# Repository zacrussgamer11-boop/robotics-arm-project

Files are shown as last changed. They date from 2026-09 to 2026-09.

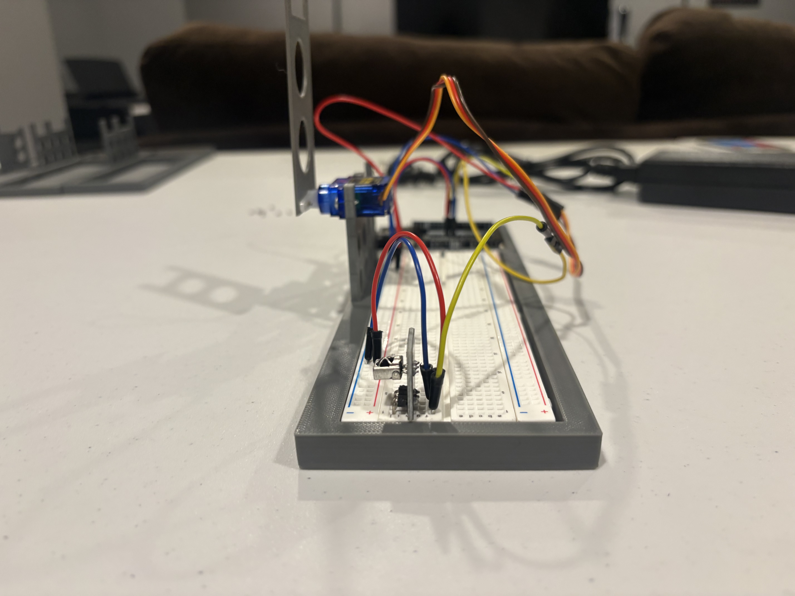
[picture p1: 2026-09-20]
project_info/V1 Complete/PHOTOS/IMG_8291.jpg

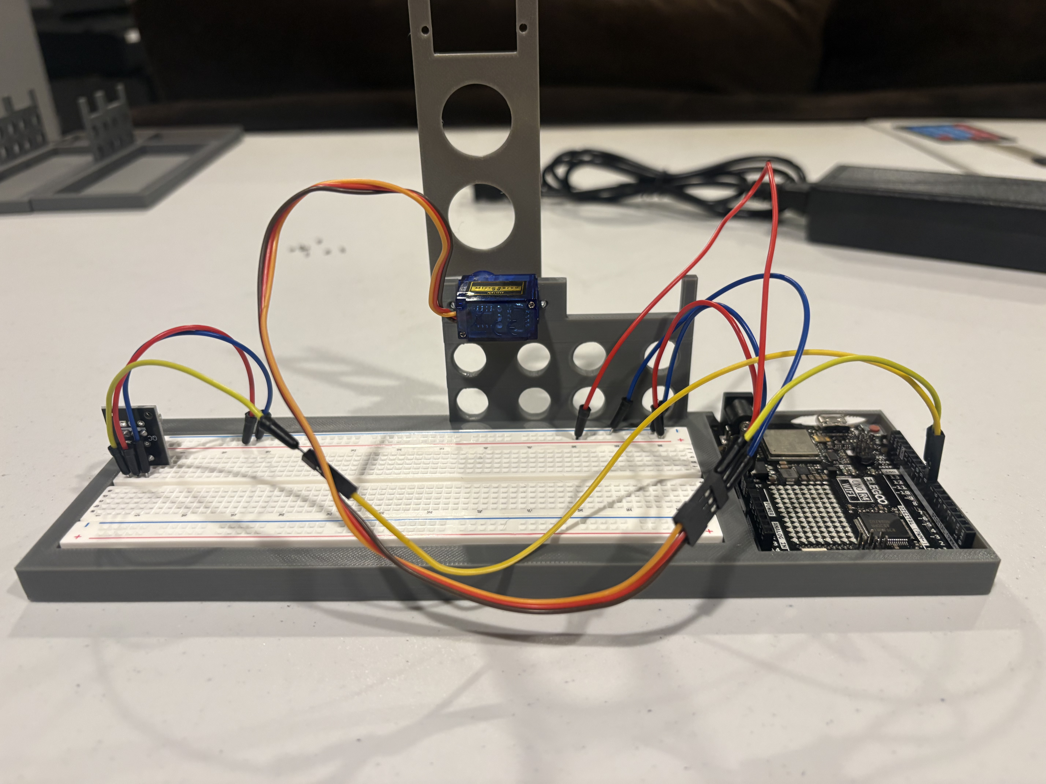
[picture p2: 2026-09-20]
project_info/V1 Complete/PHOTOS/IMG_8292.jpg

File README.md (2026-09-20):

# Robotics Arm Project

Built By zacrussgamer11
- Open Source for anybody to use
- Enjoy what I have built and use as a framework for your own projects!
- No promise anything will work as intended, everything you need will be included

Arduino UNO R4 WiFi robotics learning project.

## Current progress

- Learned breadboard basics
- Controlled an LED
- Used a pushbutton as input
- Read a potentiometer
- Controlled a servo with a potentiometer
- Added an LED movement indicator
- Added movement tolerance/deadband

## Current hardware

- Arduino UNO R4 WiFi
- Breadboard
- Potentiometer
- Servo motor
- LED
- 220 ohm resistor
- IR Sensor

## Current phase

Phase 1 - Single joint servo control

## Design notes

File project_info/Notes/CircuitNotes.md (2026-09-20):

# Build Notes - All Circuit Files can be found in the Hardware folder

## Version 1
    Plan - One servo moving a single arm forward and backwards being controlled by a remote control using a ir receiver

    ## Circuit V1
        ## IR Reciever
        - In the circuit diagram it uses a different model of IR, it is meant as representation of my circuit.
        - My Physical module uses G = GND, R = 5V, Y = signal (D8). Frontfacing the GND needs to be left most wire, PWR (5V) needs to be middle, and out needs to be most right. (If you are using this as a framework please check independently your own specific format)
        ## Servo
        - On the diagram the Signal and PWR terminals are swapped aswell, again please check your own framework and what connection points you have yourself.

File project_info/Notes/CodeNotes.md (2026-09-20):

## Code Notes

## V0.1 - Sep 19 - 1.38AM - Finished
    Initial Hardware Validation. Legacy proof of concept. Code deprecated, removed, and nonexistent. Potentiometer moved a servo which triggered a LED to light.

## V1 - Current

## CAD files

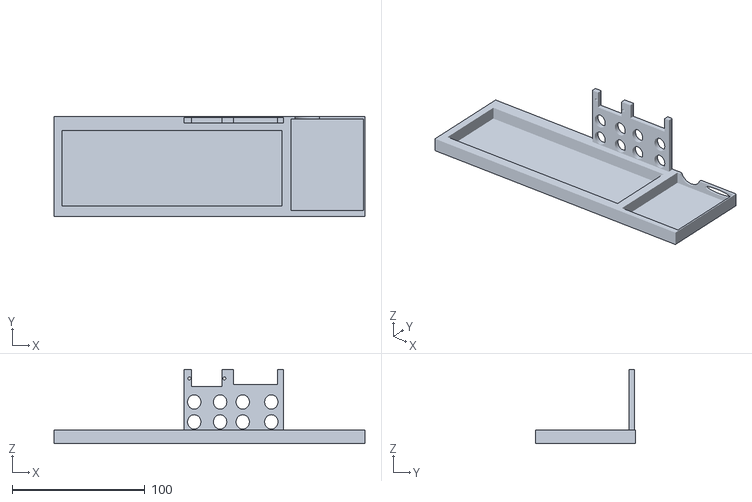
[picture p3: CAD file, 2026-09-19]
project_info/V1 Complete/HARDWARE/Mechanical/Base of robot/Base Mount V1.3.stl
234.0 x 75.5 x 56.0

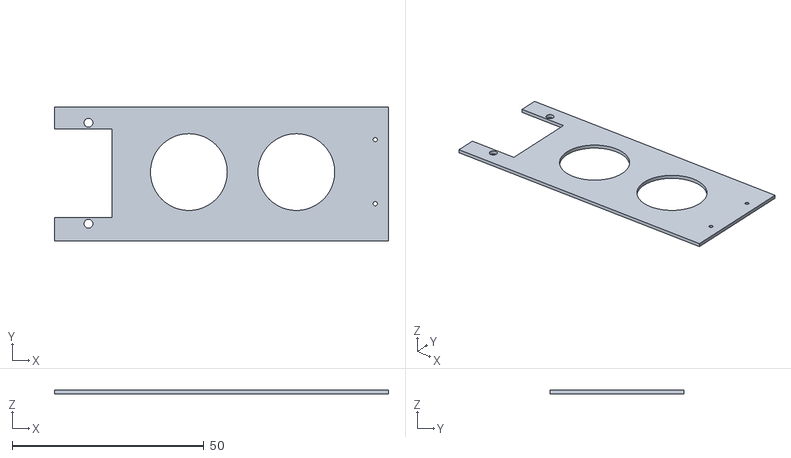
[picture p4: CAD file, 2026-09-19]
project_info/V1 Complete/HARDWARE/Mechanical/Joints/Joint 1/Joint 1 V1.2.stl
87.0 x 35.0 x 1.00

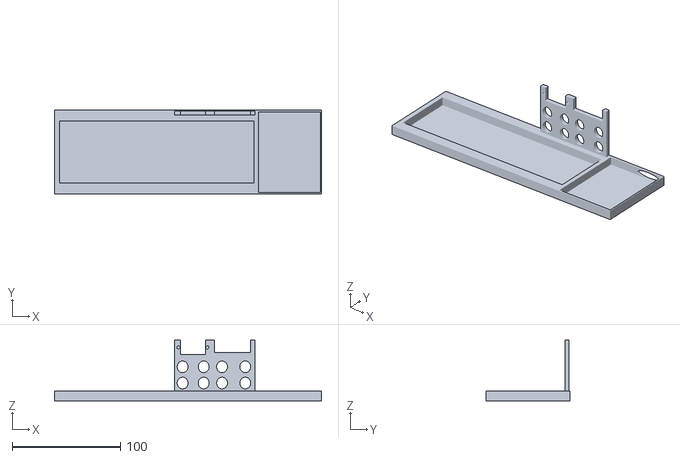
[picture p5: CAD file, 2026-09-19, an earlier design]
project_info/V1 Complete/HARDWARE/Mechanical/Base of robot/Base Mount V1.1.stl
247.0 x 78.0 x 56.0

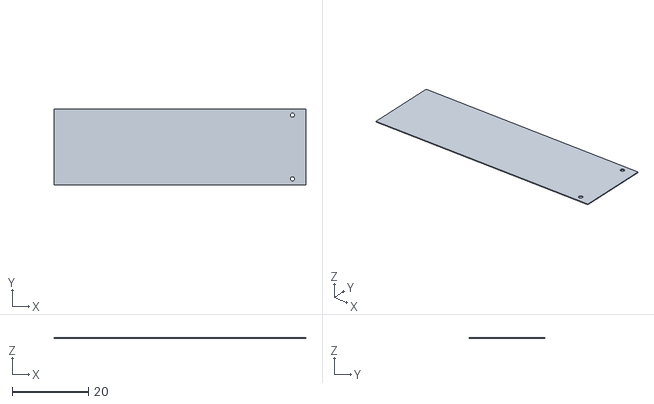
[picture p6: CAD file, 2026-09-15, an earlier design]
project_info/V1 Complete/HARDWARE/Mechanical/Joints/Joint 1/Joint 1 V1.stl
66.0 x 20.0 x 0.2

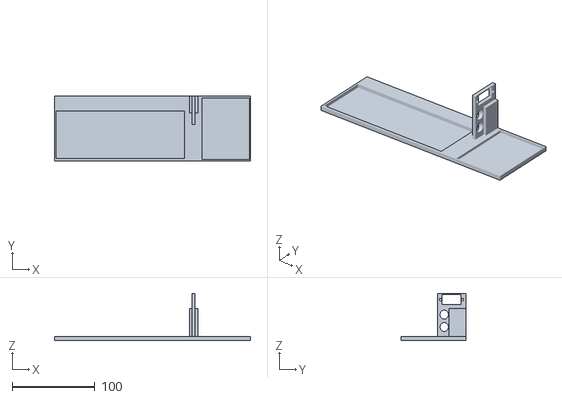
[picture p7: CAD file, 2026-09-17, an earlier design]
project_info/V1 Complete/HARDWARE/Mechanical/Base of robot/Base Mount V1.stl
237.0 x 78.0 x 57.0

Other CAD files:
project_info/V1 Complete/HARDWARE/Mechanical/Joints/Joint 1/Joint 1 V1.1.stl
project_info/V1 Complete/HARDWARE/Mechanical/Base of robot/Base Mount V1.2.stl

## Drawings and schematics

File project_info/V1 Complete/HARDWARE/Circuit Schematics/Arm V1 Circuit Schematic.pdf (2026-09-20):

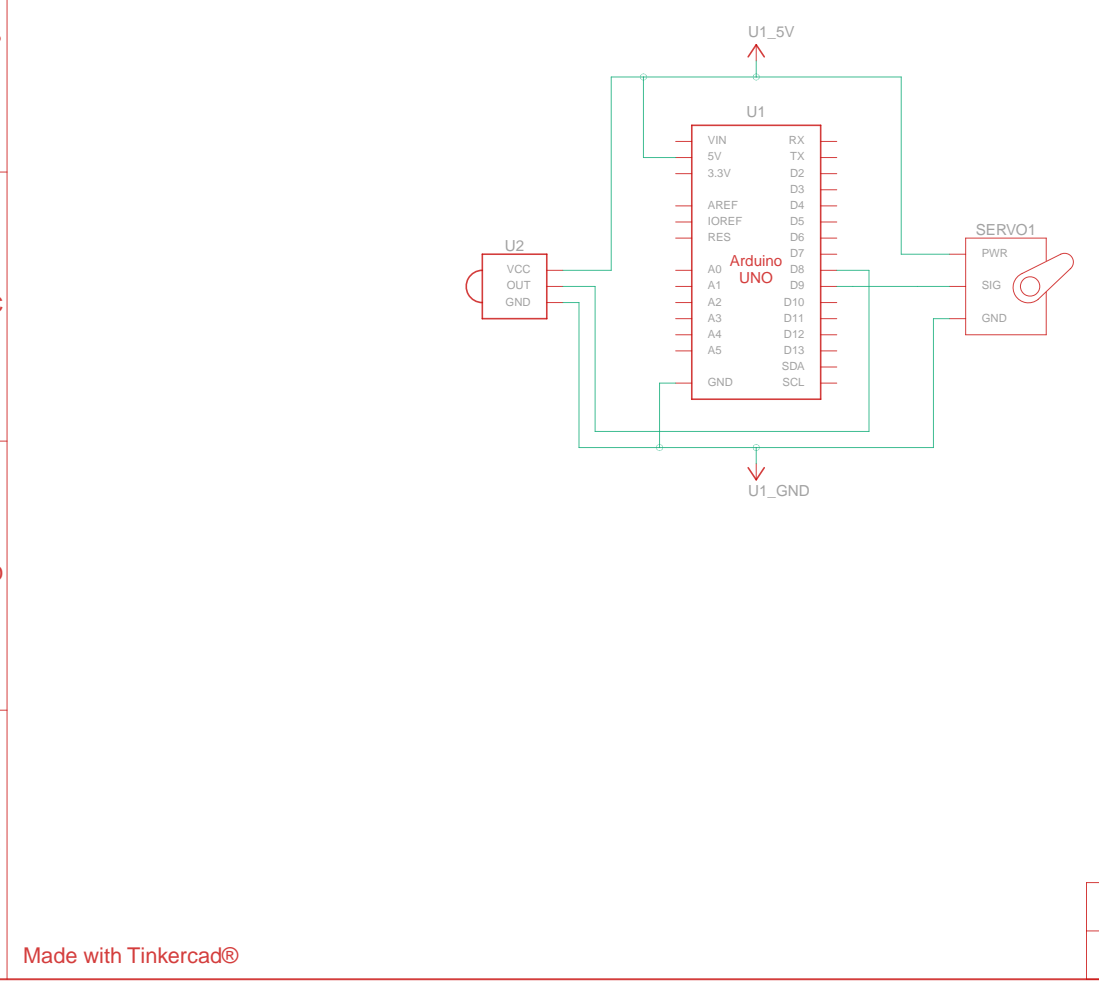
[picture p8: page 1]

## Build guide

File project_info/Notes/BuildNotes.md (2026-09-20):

# Build Notes - All .STL files can be found in the Hardware folder

## Version 1
    Plan - One servo moving a single arm forward and backwards being controlled by a remote control using a ir receiver

    ## Servo Horn
        - Screw hole diameter: 1.1mm
        - Peice width: 1.5mm
        - Using stock plastic horn
        - 3D - Printed arm will use
        - Tinkercad used for first prototype

    ## Base
        Base V1
        - This will mount the arduino on a flat bed, make a 90* wall and then attach the servo onto that
        - Housing for breadboard too small, when trying to back the servo into its mount the space was too small, entire thing warped, and was incorrectly printed
        Base V1.1
        - Hoping it goes better lol, made sure the breadboard could fit this time, made the entire plate thicker so it wont warp as much or at all, made the inlets deeper so the electronics seat better + added a hole to connect usbc to the project, I also made the screw holes .1mm tinier so the thread screws can tap better when mounting the servo, I also removed any unnessisarry overhangs as they lead to print errors and surface issues.
        Base V1.2
        - Bread board and arduino properly fit allowing room also for their plug ins.
        - Need the screw holes to mount the servo a tiny bit tinier but right now it friction fits on but I want to assure a stable mount
        Base V1.3
        - Smaller screw holes.
    
    ## Joint 1
        Joint V1
        - Currently a square with tiny holes to mount to the servo horn
        Joint V1.1
        - allowed bracing for a second servo to attach onto the motor, and put holes in the middle of the square to lighten up the load
        Joint V1.2
        - had to make the screw holes smaller

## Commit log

2026-09-15 Add current servo controller code
2026-09-15 Working on the first joint
    [Joint 1 V1.stl]
2026-09-17 Working on V1.1 of the base
    [Base Mount V1.1.stl, Base Mount V1.stl, Joint 1 V1.stl]
2026-09-19 Finishing V1
    [Base Mount V1.1.stl, Base Mount V1.2.stl, Base Mount V1.3.stl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]
2026-09-19 V1 Code is starting with the full prototype being built
    [Base Mount V1.1.stl, Base Mount V1.2.stl, Base Mount V1.3.stl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]
2026-09-20 Starting New Code to finalize the first version of robot arm 1.0
    [Base Mount V1.1.stl, Base Mount V1.2.stl, Base Mount V1.3.stl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]
2026-09-20 Optimization for sorting and project details
    [Base Mount V1.1.stl, Base Mount V1.2.stl, Base Mount V1.3.stl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]
